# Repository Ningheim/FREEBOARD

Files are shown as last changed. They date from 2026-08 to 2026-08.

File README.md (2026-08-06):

# FREEBOARD
A 60% RGB Backlit Keyboard with a OLED display, rotary encoder, and adjustable inclination stands.

This keyboard is powered by an Orpheus/Raspberry Pi Pico and an additional MCP23017 for extra GPIO pins. The firmware is entirely coded in [QMK](https://qmk.fm/) and the case is a little wider than a Framework 13 for reference, at about 320x165mm it's made to be compact and accessible to be used alongside a laptop. I made this because I wanted to fix a lot of things with the layout of other wormier and logitech keyboards where the keys weren't as inline as I'd hoped whilst still including function keys and appealing RGB factors.

## Here are the pictures to the project
### Intended Layout ([Plate Generator](https://kbplate.ai03.com/)):
LAYOUT

### Schematic (KiCAD):
SCHEMATIC

### PCB (KiCAD):
PCB
FINALPCB

### CASE (Onshape [[Document Link]](https://cad.onshape.com/documents/8cd69c605bee1d154198ffc3/w/f18789aa034f433dfb01300c/e/379cd418fcd399b0823d03fd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))
CASE

## Case Assembly
You can use adhesive for some of the parts but it isn't required as they should sit flush without any glue, you can also sand things down to fit flush if your 3d printed had a printing issue. All of the parts I'm naming in this section have corresponding names in the onshape document.

1. Put the `Plastic Spacer` in first, then the `Plastic Window` into the slot on the inside of the `Base Case`, The window is meant to be made out of clear material like transparent plastic or something so you can see the Silkscreen design on the bottom side of the board.
2. Cut a two 1mm diameter rods to 64mm and Thread each one through the holes of each set of tilt stands you as shown in the assembly tab on the onshape document. The stands should be able to turn/revolve around the axis of the rods, and you can make the rods of any material it just has to be firm. To lock the rods in, melt plastic or insert rubber friction pads into each of the 6 empty rectangular indents on the back of the `Base Case`
3. Then you can put in the PCB with the `Plate` ontop of it. Now we have the `Top Cover` and `Translucent Emblem` left, so put the `Translucent Emblem` into the matching cutout on the `Top Cover`, and insert those joined pieces into the top of the case, to keep everything pressed down. Lastly, add the encoder knob and you're done!

## How To Flash
Freeboard uses QMK Firmware running on a Raspberry Pi Pico. The firmware source is available in firmware/freeboard.

The firmware supports:
An 81-key matrix
91 SK6812MINI-E RGB LEDs
An I2C OLED display
A rotary encoder connected through an MCP23017 GPIO expander
Media and RGB controls through a function layer

To start building the firmware, install and configure the QMK development environment, then copy the Freeboard firmware into your QMK installation:

cp -a firmware/freeboard ~/qmk_firmware/keyboards/
cd ~/qmk_firmware
qmk clean
qmk compile -kb freeboard -km default

After a successful build, the flashable firmware will be located at:

~/qmk_firmware/freeboard_default.uf2

#### Flashing Sequence
Unplug Freeboard from the computer.
Hold the BOOTSEL button on the Raspberry Pi Pico.
While continuing to hold BOOTSEL, connect the keyboard to the computer using USB.
Release BOOTSEL when a removable drive named RPI-RP2 appears.
Copy freeboard_default.uf2 onto the RPI-RP2 drive.
The drive will disconnect automatically and the keyboard will restart with the new firmware.
Flashing future updates

Hold Fn and press Esc to enter the RP2040 bootloader. When the RPI-RP2 drive appears, copy the newly compiled freeboard_default.uf2 onto it.

## CONTROLS
The Fn key is located between Right Alt and Left Arrow.

Input	Action
Rotate encoder	Adjust volume
Press encoder	Mute or unmute
Fn + Esc	Enter the bootloader
Fn + Home	Toggle RGB lighting
Fn + Page Up	Select the next RGB effect
Fn + Page Down	Select the previous RGB effect
Fn + Up	Increase RGB brightness
Fn + Down	Decrease RGB brightness
Fn + Left	Decrease RGB hue
Fn + Right	Increase RGB hue
Fn + End	Increase RGB animation speed
RGB brightness is limited in firmware because all 91 LEDs are powered from USB VBUS. Increasing the limit could exceed the available USB current.

## BOM
| Item | Cost |
|---|---|
| PCB | $37.84 |
| Switches, Keycaps, Encoder, Display | $15.00 |
| Plastic Case | Free (Printing Legion) |
| Electronic Components | $22.18 |
| Display Connector | $7.00 |
| Buffer for shipping and fees | $5.00 |
| **Total** | **~$88.02** |

Note: The BOM file itself is in ~\FREEPCB\PRODUCTION, and the keycaps, switches, stabilizers, and encoder all probably have to be bought from an external retailer. So prices may vary.

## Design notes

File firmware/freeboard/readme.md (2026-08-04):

# Freeboard

Custom 81-key keyboard using a Raspberry Pi Pico, 91 SK6812MINI-E LEDs,
an I2C OLED, and a rotary encoder connected through an MCP23017 expander.

* Keyboard Maintainer: [Freedom Nyadroh](https://github.com/ningheim)
* Controller: Raspberry Pi Pico (RP2040)
* Matrix: 6 rows by 15 columns, COL2ROW
* RGB: 91 serial LEDs on GP21 (81 key lights and 10 decorative lights)
* I2C: I2C1 on GP22/GP26
* Encoder: MCP23017 address 0x20, GPA0/GPA1/GPA2

Make example for this keyboard (after setting up your build environment):

    make freeboard:default

Flashing example for this keyboard:

    make freeboard:default:flash

See the [build environment setup](https://docs.qmk.fm/#/getting_started_build_tools) and the [make instructions](https://docs.qmk.fm/#/getting_started_make_guide) for more information. Brand new to QMK? Start with our [Complete Newbs Guide](https://docs.qmk.fm/#/newbs).

## Installation

Copy this entire `freeboard` directory to:

    ~/qmk_firmware/keyboards/freeboard

For QMK 0.33 and newer, keep the board metadata named `keyboard.json`.
Do not rename it to `info.json`.

If QMK's own Python source was previously edited, restore it first:

    cd ~/qmk_firmware
    git restore lib/python/qmk/keyboard.py

Then verify and compile:

    qmk clean
    qmk list-keyboards | grep freeboard
    qmk compile -kb freeboard -km default

The compiled UF2 should be placed in the root of the QMK firmware directory.

## Default controls

The encoder changes volume and its push switch toggles mute. Hold the key
immediately to the left of the arrow cluster to access the Fn layer. The Fn
layer contains RGB controls; Fn+Esc enters the RP2040 bootloader.

The OLED configuration assumes the common 128x32 SSD1306 display at address
0x3C. For a 128x64 display, add `#define OLED_DISPLAY_128X64` to `config.h`.

## RGB power limit

The PCB powers all 91 LEDs from USB VBUS. Firmware therefore limits the maximum
RGB brightness. Raising this limit can exceed the USB port's current budget,
especially with white or pale effects.

## Bootloader

Enter the bootloader in 3 ways:

* **Bootmagic reset**: Hold down the key at (0,0) in the matrix (usually the top left key or Escape) and plug in the keyboard
* **Physical reset button**: Briefly press the button on the back of the PCB - some may have pads you must short instead
* **Keycode in layout**: Press the key mapped to `QK_BOOT` if it is available

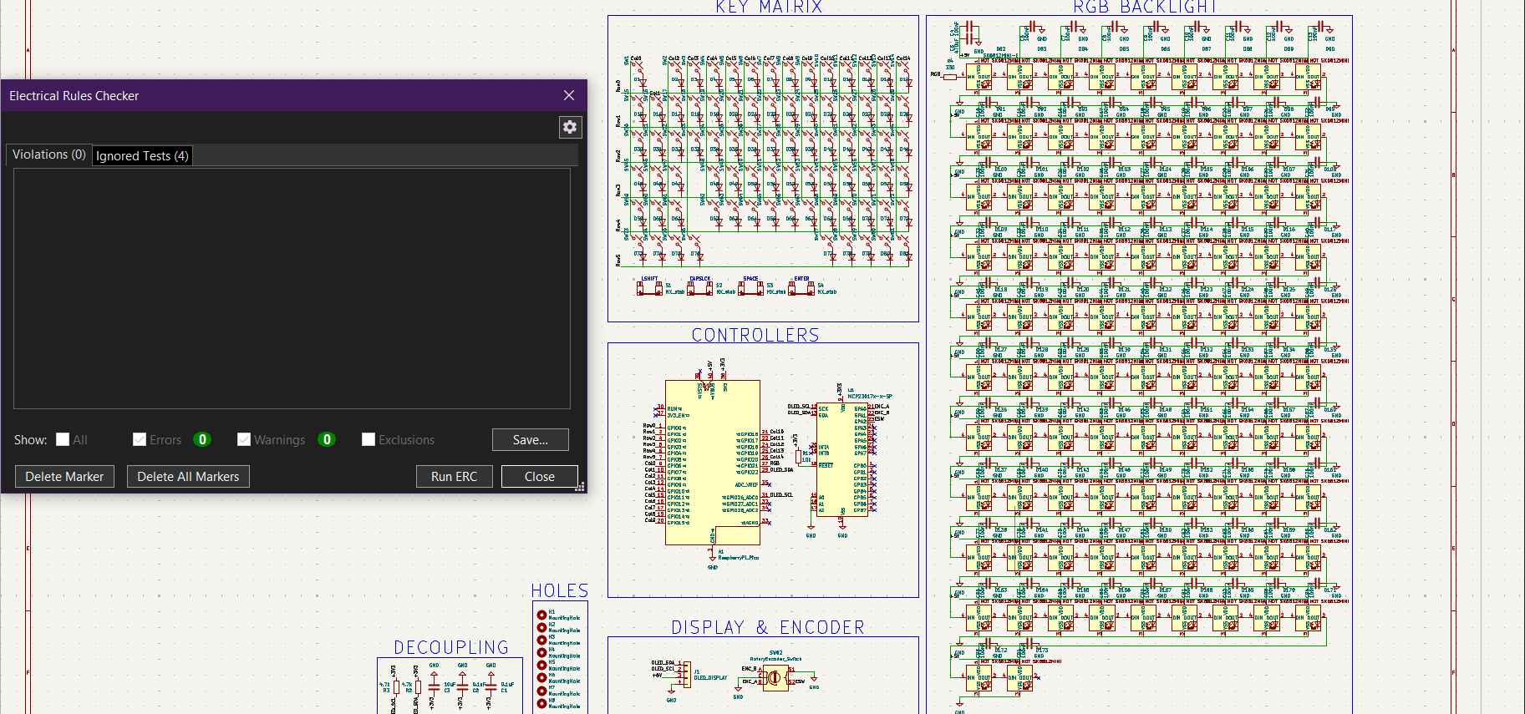
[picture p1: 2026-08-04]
FREEASSETS/SCHEMATIC.png

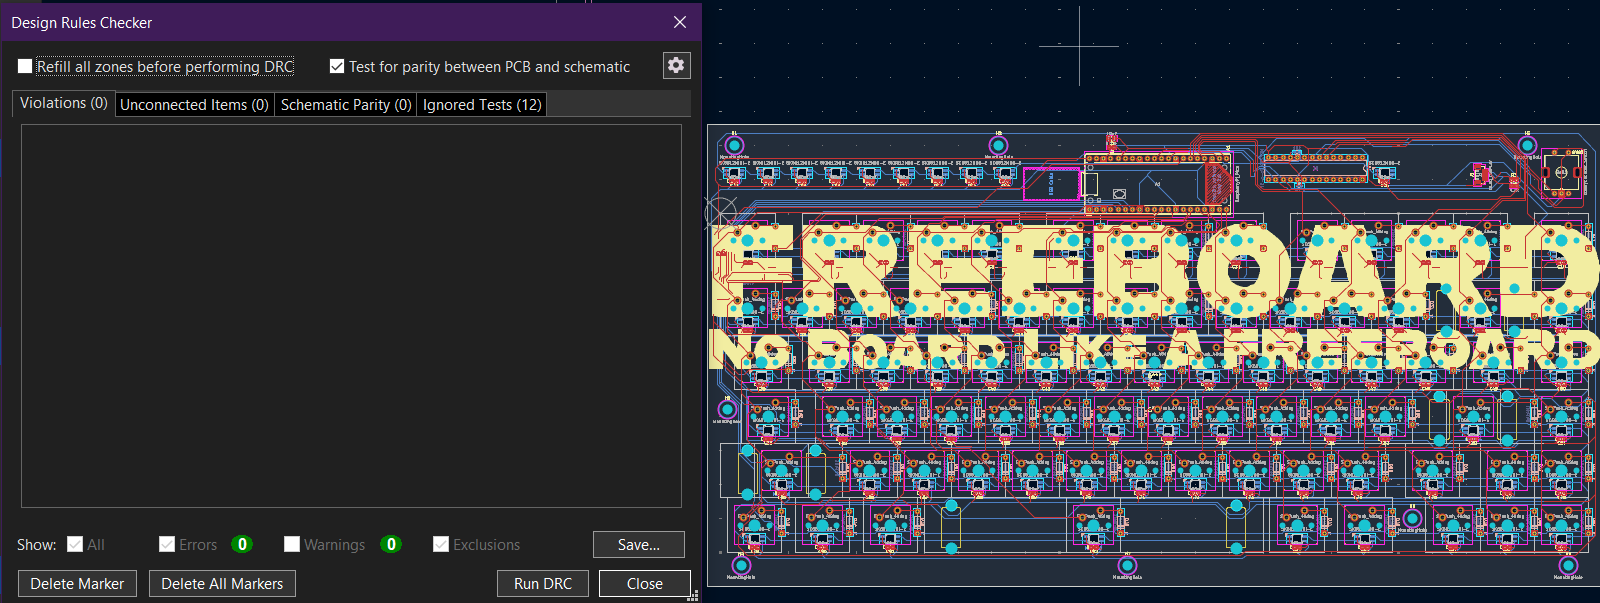
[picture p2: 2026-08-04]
FREEASSETS/PCB.png

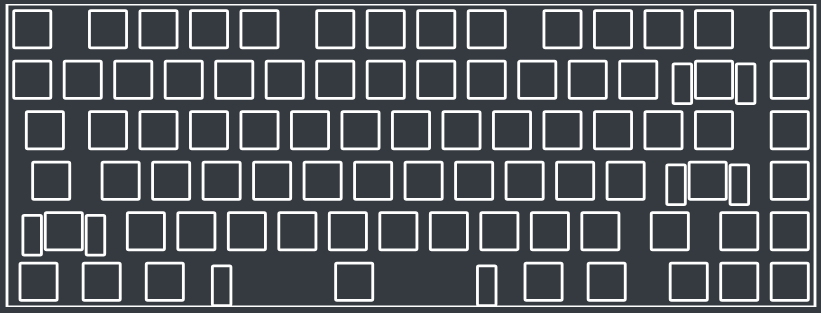
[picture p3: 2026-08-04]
FREEASSETS/LAYOUT.png

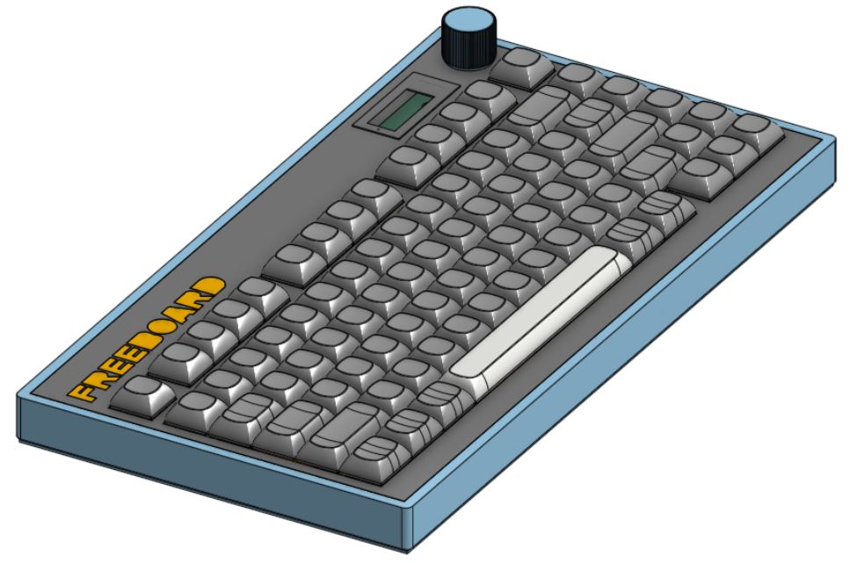
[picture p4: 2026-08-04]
FREEASSETS/CASE.png

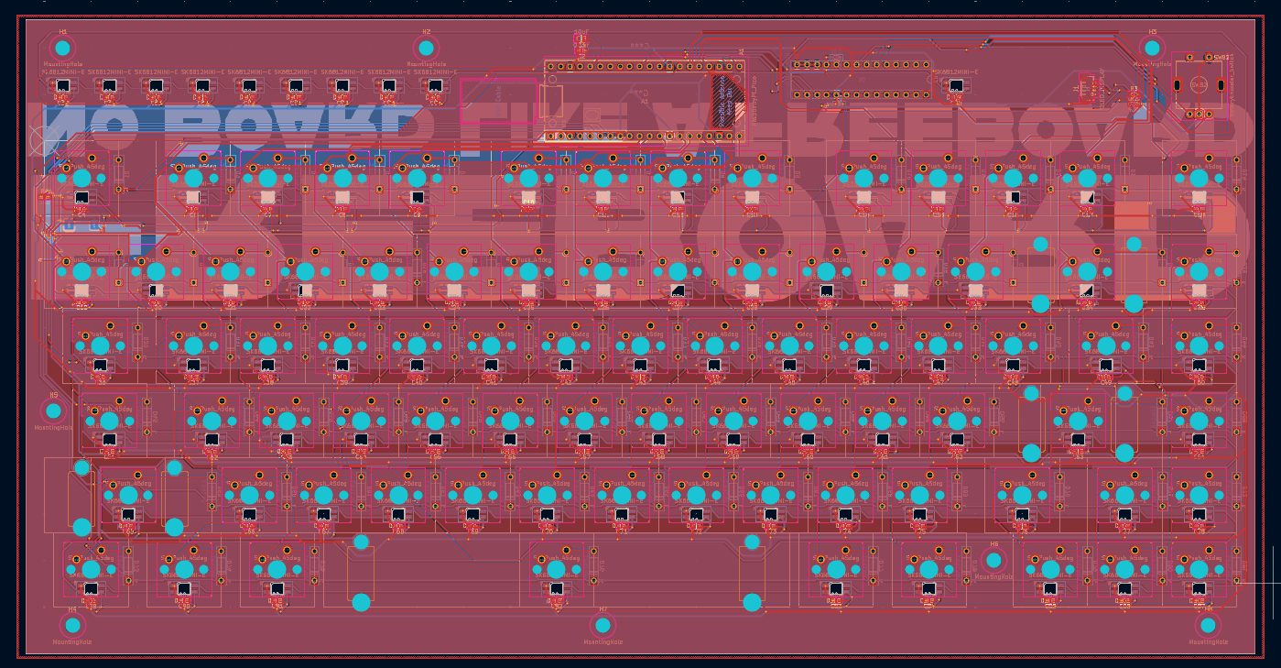
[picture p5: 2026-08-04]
FREEASSETS/FINALPCB.png

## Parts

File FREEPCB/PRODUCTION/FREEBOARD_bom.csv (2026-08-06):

Designator | Footprint | Quantity | Value | LCSC Part # | Link
A1 | RaspberryPi_Pico_Common_THT | 1 | RaspberryPi_Pico | C7203003 | https://www.lcsc.com/product-detail/C7203003.html?s_z=n_q_raspberry%2520pi%2520pico
C1, C2 | 603 | 2 | 0.1uF | C19185645 | https://www.lcsc.com/product-detail/C19185645.html?s_z=n_q_C19185645&globalKeyword=C19185645
C10, C11, C12, C13, C14, C15, C16, C17, C18, C19, C20, C21, C22, C23, C24, C25, C26, C27, C28, C29, C30, C31, C32, C33, C34, C35, C36, C37, C38, C39, C4, C40, C41, C42, C43, C44, C45, C46, C47, C48, C49, C50, C51, C52, C53, C54, C55, C56, C57, C58, C59, C6, C60, C61, C62, C63, C64, C65, C66, C67, C68, C69, C7, C70, C71, C72, C73, C74, C75, C76, C77, C78, C79, C8, C80, C81, C82, C83, C84, C85, C86, C87, C88, C89, C9, C90, C91, C92, C93, C94, C95 | 603 | 91 | 100nF | C19185645 | https://www.lcsc.com/product-detail/C19185645.html?s_z=n_q_C19185645&globalKeyword=C19185645
C3 | 805 | 1 | 10uF | C576646 | https://www.lcsc.com/product-detail/C576646.html?s_z=n_q_C576646&globalKeyword=C576646
C5 | CP_EIA-7343-31_Kemet-D_HandSolder | 1 | 470uF | C600572 | https://www.lcsc.com/product-detail/C600572.html?s_z=n_q_C600572&globalKeyword=C600572
D1, D10, D11, D12, D13, D14, D15, D16, D17, D18, D19, D2, D20, D21, D22, D23, D24, D25, D26, D27, D28, D29, D3, D30, D31, D32, D33, D34, D35, D36, D37, D38, D39, D4, D40, D41, D42, D43, D44, D45, D46, D47, D48, D49, D5, D50, D51, D52, D53, D54, D55, D56, D57, D58, D59, D6, D60, D61, D62, D63, D64, D65, D66, D67, D68, D69, D7, D70, D71, D72, D73, D74, D75, D76, D77, D78, D79, D8, D80, D81, D9 | D_DO-35_SOD27_P7.62mm_Horizontal | 81 | 1N4148 | C258182 | https://www.lcsc.com/product-detail/C258182.html?s_z=n_q_C258182&globalKeyword=C258182
D100, D101, D102, D103, D104, D105, D106, D107, D108, D109, D110, D111, D112, D113, D114, D115, D116, D117, D118, D119, D120, D121, D122, D123, D124, D125, D126, D127, D128, D129, D130, D131, D132, D133, D134, D135, D136, D137, D138, D139, D140, D141, D142, D143, D144, D145, D146, D147, D148, D149, D150, D151, D152, D153, D154, D155, D156, D157, D158, D159, D160, D161, D162, D163, D164, D165, D166, D167, D168, D169, D170, D171, D172, D82, D83, D84, D85, D86, D87, D88, D89, D90, D91, D92, D93, D94, D95, D96, D97, D98, D99 | SK6812MINI-E_fixed | 91 | SK6812MINI-E | C5149201 | https://www.lcsc.com/product-detail/C5149201.html?s_z=n_q_C5149201&globalKeyword=C5149201
J1 | JST_SH_BM04B-SRSS-TB_1x04-1MP_P1.00mm_Vertical | 1 | OLED_DISPLAY | C160390 | https://www.lcsc.com/product-detail/C160390.html?s_z=n_q_C160390&globalKeyword=C160390
R1 | 603 | 1 | 10k | C2906982 | https://www.lcsc.com/product-detail/C2906982.html?s_z=n_q_C2906982&globalKeyword=C2906982
R2, R3 | 603 | 2 | 4.7k | C99782 | https://www.lcsc.com/product-detail/C99782.html?s_z=n_q_C99782&globalKeyword=C99782
R4 | 603 | 1 | 330 | C105881 | https://www.lcsc.com/product-detail/C105881.html?s_z=n_q_C105881&globalKeyword=C105881
S1 | STAB_MX_2u | 1 | MX_stab
S2, S3 | STAB_MX_2.25u | 2 | MX_stab
S4 | STAB_MX_6.25u | 1 | MX_stab
SW1, SW10, SW11, SW12, SW13, SW14, SW15, SW16, SW17, SW18, SW19, SW2, SW20, SW21, SW22, SW23, SW24, SW25, SW26, SW27, SW28, SW29, SW3, SW30, SW31, SW32, SW33, SW34, SW35, SW36, SW37, SW38, SW39, SW4, SW40, SW41, SW42, SW43, SW44, SW45, SW46, SW47, SW48, SW49, SW5, SW50, SW51, SW52, SW53, SW54, SW55, SW56, SW57, SW58, SW59, SW6, SW60, SW61, SW62, SW63, SW64, SW65, SW66, SW67, SW68, SW69, SW7, SW70, SW71, SW72, SW73, SW74, SW75, SW76, SW77, SW78, SW79, SW8, SW80, SW81, SW9 | SW_MX_1u | 81 | SW_Push_45deg
SW82 | ROT_Alps_EC11E-Switch | 1 | RotaryEncoder_Switch
U1 | DIP-28_W7.62mm | 1 | MCP23017x-x-SP | C558584 | https://www.lcsc.com/product-detail/C558584.html?s_z=n_q_C558584&globalKeyword=C558584

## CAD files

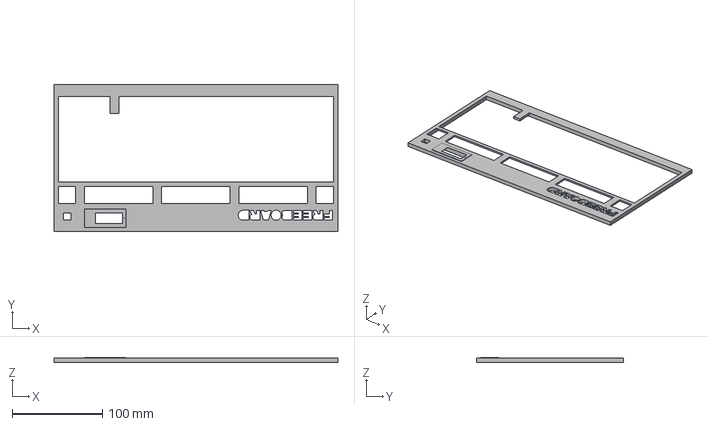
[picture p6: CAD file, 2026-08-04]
FREECAD/CASE PARTS - STEP/Case - TopCase.step
315.3 x 162.9 x 5.50 mm

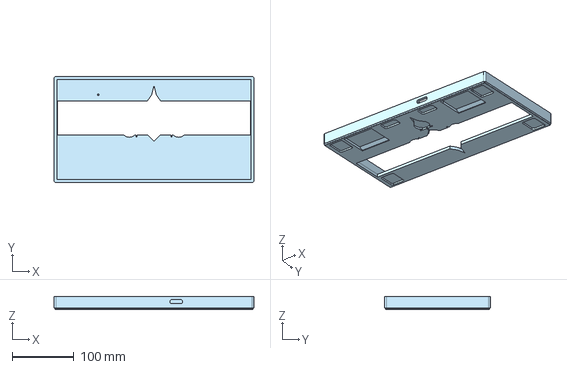
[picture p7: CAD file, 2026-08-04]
FREECAD/CASE PARTS - STEP/Case - Base Case.step
324.3 x 171.9 x 20.4 mm

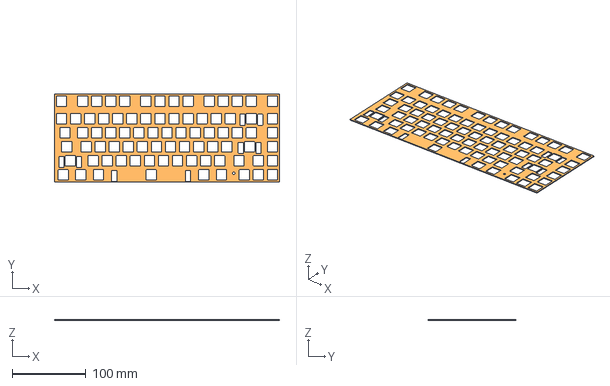
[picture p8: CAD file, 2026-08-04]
FREECAD/CASE PARTS - STEP/Case - Plate.step
304.8 x 119.1 x 1.00 mm

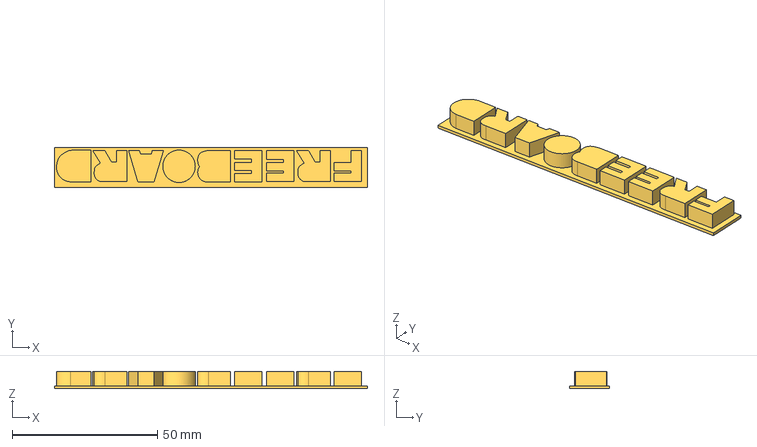
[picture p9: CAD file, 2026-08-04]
FREECAD/CASE PARTS - STEP/Case - Translucent Emblem.step
107.6 x 13.8 x 6.00 mm

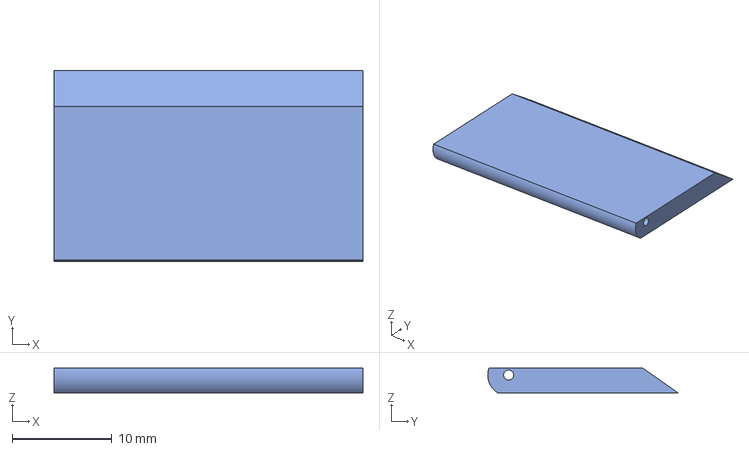
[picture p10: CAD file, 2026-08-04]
FREECAD/CASE PARTS - STEP/Case - SmallStand1.step
31.0 x 19.1 x 2.50 mm

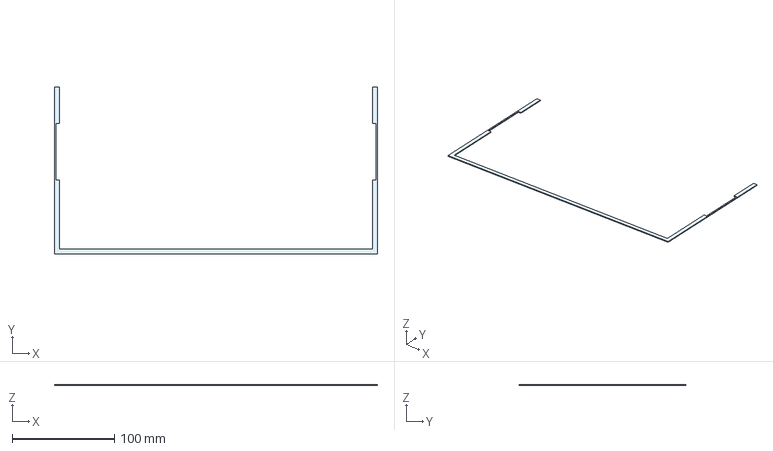
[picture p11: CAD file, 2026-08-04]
FREECAD/CASE PARTS - STEP/Case - Plastic Spacer.step
315.3 x 162.9 x 1.00 mm

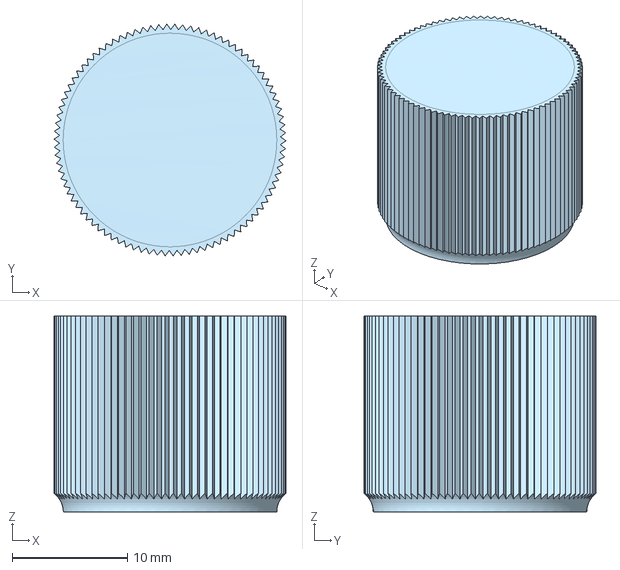
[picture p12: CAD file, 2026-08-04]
FREECAD/CASE PARTS - STEP/Case - Encoder Knob.step
20.2 x 20.1 x 17.0 mm

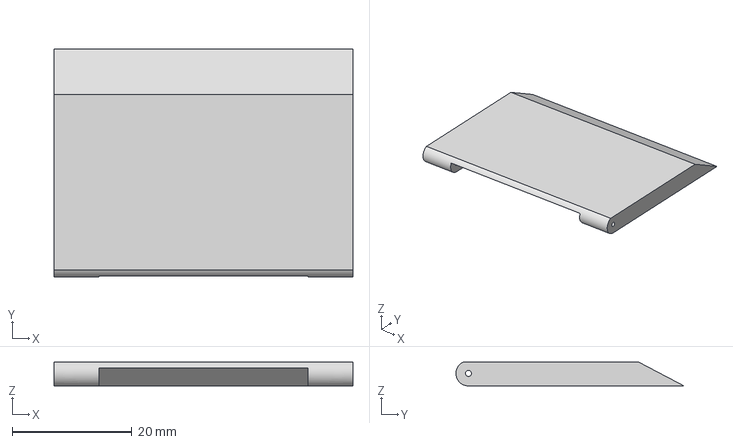
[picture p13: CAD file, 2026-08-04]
FREECAD/CASE PARTS - STEP/Case - BigStand2.step
50.0 x 38.1 x 4.00 mm

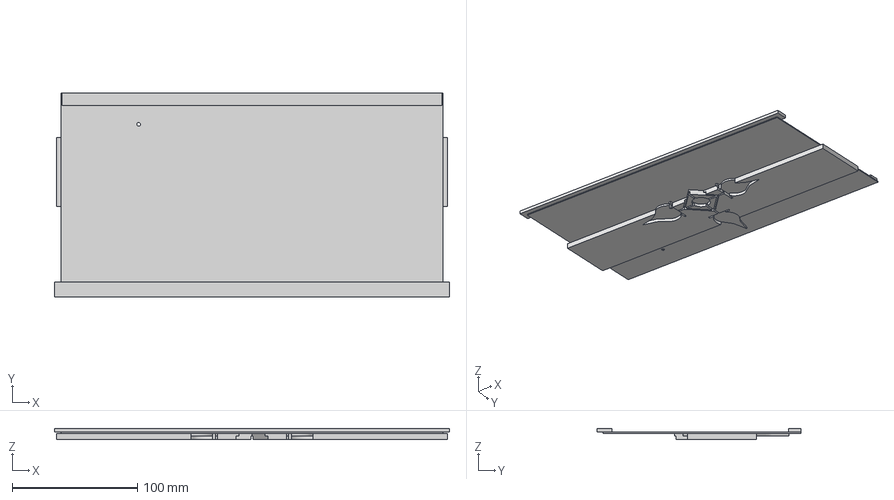
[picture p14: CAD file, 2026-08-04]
FREECAD/CASE PARTS - STEP/Case - Plastic Window.step
315.3 x 162.9 x 9.06 mm

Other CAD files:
FREECAD/CASE PARTS - STEP/Case - SmallStand2.step
FREECAD/CASE PARTS - STEP/Case - BigStand1.step
FREECAD/CASE PARTS - STL/Case - Base Case.stl
FREECAD/CASE PARTS - STL/Case - BigStand1.stl
FREECAD/CASE PARTS - STL/Case - BigStand2.stl
FREECAD/CASE PARTS - STL/Case - Encoder Knob.stl
FREECAD/CASE PARTS - STL/Case - Plastic Spacer.stl
FREECAD/CASE PARTS - STL/Case - Plastic Window.stl
FREECAD/CASE PARTS - STL/Case - Plate.stl
FREECAD/CASE PARTS - STL/Case - SmallStand1.stl
FREECAD/CASE PARTS - STL/Case - SmallStand2.stl
FREECAD/CASE PARTS - STL/Case - TopCase.stl
FREECAD/CASE PARTS - STL/Case - Translucent Emblem.stl

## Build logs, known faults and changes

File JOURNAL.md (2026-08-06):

# 7/27/2026
[LAPSE](https://lapse.hackclub.com/timelapse/CAK7ywI3q3qV)

**Total time spent: 3 hours**

I studied keyboard anatomy and creation for a while before starting this project. I now know I need three things to actually make this keyboard:

- **PCB**
- **Plate**
- **Case**

And as simple as that makes it look, I know it will be a long a grueling process especially since this is the first real keyboard I've made. Today I finished the keyboard matrix, taking inspiration from the Wormier 60% and 65% keyboards for the layout I mapped below:



Next session I'll be routing the RGB LEDs, OLED display, rotary encoder, and external SoM connector in the schematic.

The layout is a 60%-style board with the function row and PrintScreen key included. It'll have a small margin at the top for an RGB text badge reading "FREEBOARD," along with an OLED screen and a backlit rotary encoder. There will also be a dedicated LED for Caps Lock indication. I took some inspiration from the Logitech G PRO keyboard I currently use, just scaled down a bit. My goal is for this keyboard to sit on top of a Framework 13's keyboard, for gaming and general use.

This was a pretty difficult process, but I'm super excited and feeling good about the progress so far.

*(Also, sorry about the video playing during the lapse, I was watching Mat Armstrong to stay sane through the whole process.)*

# 7/28/2026
[LAPSE](https://lapse.hackclub.com/timelapse/dE8z8UnWDV4i) [LAPSE](https://lapse.hackclub.com/timelapse/KWQZoNLu7TrB)

**Total time spent: 4 hours**

Made a lot of nice progress with tracing. I troubleshot the switch matrix and I believe it's good as of now. It's easily subject to change after I add the rotary encoder. I'm not exactly sure how I'm supposed to incorporate the encoder right now. All of the other components are pretty straightforward except for that. I'm running out of pins on the Pico so I'm searching for ways to conserve as many as possible. Today I got Claude to help me code a JSON for a keyboard switch layout/plate and I finally got it looking a little more professional. Here's the polished version of what my keyboard layout will look like:



Once I get a response in the channel for help with wiring the power bus lines and the rotary encoder I'll resume and finish off the schematic process for now. I'm liking how it all looks so far. This is the schematic as of right now, once I finish the schematic I'll separate all the groups and finalize the organization of the file:



**Okay it's me 15 hours later**, I made tremendous progress with the Schematic and I was able to almost completely finish the schematic. I haven't assigned footprints yet but everything went extremely well this session. I implemented resistors and capacitors wherever I needed them. I found out I needed them by looking at other submissions to Keeb and asking Claude a few questions. Speaking of Claude, it told me to add a fuse to the VBUS so the PCB I plan on connecting this stuff to wont completely self destruct if the RGB LEDs go crazy. But every time I added the fuse it kept giving me an error so for now I'm sticking with the error-less design. Next session I'll look into the whole fuse idea a little harder and I'll determine whether or not I'll use it; I'll also add footprints to everything and finally start working on laying out traces for the physical PCB. We're almost there!



# 7/29/2026
[LAPSE](https://lapse.hackclub.com/timelapse/rfvNHJk3dFeS)[LAPSE](https://lapse.hackclub.com/timelapse/_yMK92cxTNwy) 

**Total time spent: 6 hours**

Today I finalized the schematic and footprints.



Took me an hour to do it because I had some trouble with the fuse idea from earlier. I found out that the fuse isn't really necessary. I also understand that I could have added a 33ohm resistor in between each LED's data pins but i decided not to do that since it'd be a pain to handsolder. And I'm going to be adding mill-max hotswap sockets to my finished build. So I hope I get funded for that. I was told I would be funded for everything that would necessarily impact my project. Right now I'll list all the ammenities and complexities I decided to add to the project:
- Per-Key Backlight
- Caps Lock Indicator
- Backlit Branding Logo
- Rotary Encoder
- OLED Display
- Hotswappable Switches

Anyways later today I'll work on the PCB design itself. I'll ask around if there's anything wrong with how I made the schematic but I think I'll be moving on now!

**Its around midnight now** I got done with a 4-5 hour session and i finished organizing everything and whatnot. The board organization is 90% done but i need some rest. Tomorrow I'll finish organizing the components in a few minutes and finally start routing.



# 7/30/2026
[LAPSE](https://lapse.hackclub.com/timelapse/d9UfakixuzQQ)

**Total time spent: 6 hours**

Just started routing the PCB. It is not looking good at all. My organization is great though, but when I finished it all and went to fill the copper layer I got hundreds of errors and warnings. This was really discouraging but I know it isn't to important since all of my layouts and traces should be connected. I'll look over it again tomorrow. I suspect it's because I didn't put traces or Vias on any of the GND pads believing the layer fill would connect them all automatically. I'll try to do it manually later on.. Anyways the lapse feature has been working pretty well recently! I haven't gotten any corrupt or inaccessible files after strictly doing lapses from lapse.hackclub.com instead of any other embed or site, but, accidentally of course, I took a break to scroll tiktok and play games without pausing the recording so instead of 5 hours and 48 minutes its more like only 5 hours.



# 7/31/2026
[LAPSE](https://lapse.hackclub.com/timelapse/Ccc565L8SkLy)

**Total time spent: 4 hours**

Finished 3D modelling the PCB. it took a while but it looks extremely nice, I quickly learned how to add 3d models to a global footprint instead of editing each switch's individual one. I got the DSA keycap models from a reddit post. This is the [link](https://drive.google.com/drive/u/0/folders/0B0LNjZf_tzjWZGhwZ0VKUm9PQVE?resourcekey=0-rYUAMYD1-22Btlgdmpb0IQ) I'm really grateful to the creator. Anyways it looks like this now with all the components (Minus the oled display) modeled:



I swapped out the OLED display footprint for a `Stemma QT 4-Pin Female Connector` Because I decided I was going to connect my display via a `Header to QT` style cable from Adafruit. And in doing this, I allow the connection between the OLED display and my PCB to be a lot more flexible which would allow me to prop the display up on an incline as seen on Wormier's keyboards (I took a lot of inspiration from them, I love their designs) as seen below:



This would be both aesthetically pleasing and gives the display a little more accessibility. And now I'm tackling the GND plane issue. It took me a while to understand but now I realize I just have to connect all the GND pads together and then do the ground pour to leave no room for errors about my GND connection. I've routed about 45% of the GND net so far and once I finish this I will be able to finally move onto the Case design which I'm pretty excited for. I'm going to make this keyboard near perfect to actually use it in place of my current TKL one. Here's how the PCB looks now (I know, beautiful 🥹) :



# 8/1/2026
[LAPSE](https://lapse.hackclub.com/timelapse/lMde7KmQML3c) [LAPSE](https://lapse.hackclub.com/timelapse/M3SkIIiRgxoi)

**Total time spent: 12 hours**

Finally completed the PCB within the first hour of this lapse. Spent the rest modelling the case. I'm double, triple, and quadruple checking each part of my layout just to make sure I don't have any miscalculations or inconsistencies with my work. This is how the finished PCB looked:



I'm modelling the case design in Onshape and I guess I'll submit an assembly demo with push-able keys later. Ok scratch that onshape is already struggling on my laptop I doubt adding push-able mates is necessary. Anyways I just finished the bottom plate of my case (for the most part) and it looks amazing imo. I'm adding a transparent plastic window in my next session but it looks like this now at 10mm of thickness:



It looks great and I'm really happy about how I added the 2 stage stands at the top, I hope they work but yeah this is basically it for now.

# 8/2/2026
[LAPSE](https://lapse.hackclub.com/timelapse/Tz_bAdnx_3QB) [LAPSE](https://lapse.hackclub.com/timelapse/NqZxc6qf-A2T)

**Total time spent: 6 hours**

I finished the entire Board body in about an hour. I'm moving onto the Firmware now. I finished modelling the Rotary Encoder Knob and Recessed the OLED Display panel a little more to allow this to keep it's low-(ish) profile silhouette. 



> Also, for anyone that's looking to model their keyboard like I did with mine, I found the DSA profile models in a Reddit thread which I'm super grateful for. Here's the google [drive link](https://drive.google.com/drive/u/0/folders/0B0LNjZf_tzjWZGhwZ0VKUm9PQVE?resourcekey=0-rYUAMYD1-22Btlgdmpb0IQ)

And I forgot to generate the BOM and fabrication files for JLCPCB or PCBWAY so I made sure to do that. Also I forgot to add the copper fill layer, it wouldn't really be that bad if I left it out but I guess it's always optimal to do so, here's how it looked:



Ok, just finished the second lapse. I'm absolutely livid at how terrible Gemini is as an LLM. It kept recommending things and making me go down rabbit holes that were completely unrelated and I had to use Gemini because I ran out of Claude credits 😭 I spent 4 hours of my life coding a dysfunctional firmware because Gemini is so redundant it's actually crazy bro. Anyway I at least mapped the keys into the JSON dictionary and I reverted the files mostly to before I started getting baited by Gemini. I'm honestly just happy I can start from a feasible position now because the amount of time I just wasted is insane. I'm sticking to Claude for life. 

# 8/3/2026
[LAPSE](https://lapse.hackclub.com/timelapse/1gnXPpYtZCP9)

**Total time spent: 1 hour**

Just some housekeeping adjustments made to the onshape file. Also I realized I forgot to share the link to the native onshape document, [so here it is](https://cad.onshape.com/documents/8cd69c605bee1d154198ffc3/w/f18789aa034f433dfb01300c/e/379cd418fcd399b0823d03fd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). I fixed some interference issues I noticed in assembly, they werent that important but I'm just making sure everything fits together smoothly. Specifically I made holes to accommodate for the hardware components a little more fairly. Took a break and failed to resume the lapse yet again though. Sad stuff


# 8/4/2026
[LAPSE](https://lapse.hackclub.com/timelapse/J0E3boF5okCd) [LAPSE](https://lapse.hackclub.com/timelapse/QhkDZo6vc7pb)

**Total time spent: 4 hours**

Just finished calculating how much this would cost, with the BOM and everything. Here are the results:

| Item | Cost |
|---|---|
| PCB | $37.84 |
| Switches, Keycaps, Encoder, Display | $15.00 |
| Plastic Case | Free (Printing Legion) |
| Electronic Components | $22.18 |
| Display Connector | $7.00 |
| Buffer for shipping and fees | $5.00 |
| **Total** | **~$88.02** |

So not that bad. I hope I have enough currency leftover to buy some RAM. Anyways, I'll be working on the Firmware later today.
A couple minutes after and I finished the firmware and the readme is complete. I'm just getting ready to ship now. I forgot to lapse I think all this time is taking a hit on my health dawg. This time I lost a lot more time though so I'll use my hackatime tracker as proof of everything:


Also the firmware:


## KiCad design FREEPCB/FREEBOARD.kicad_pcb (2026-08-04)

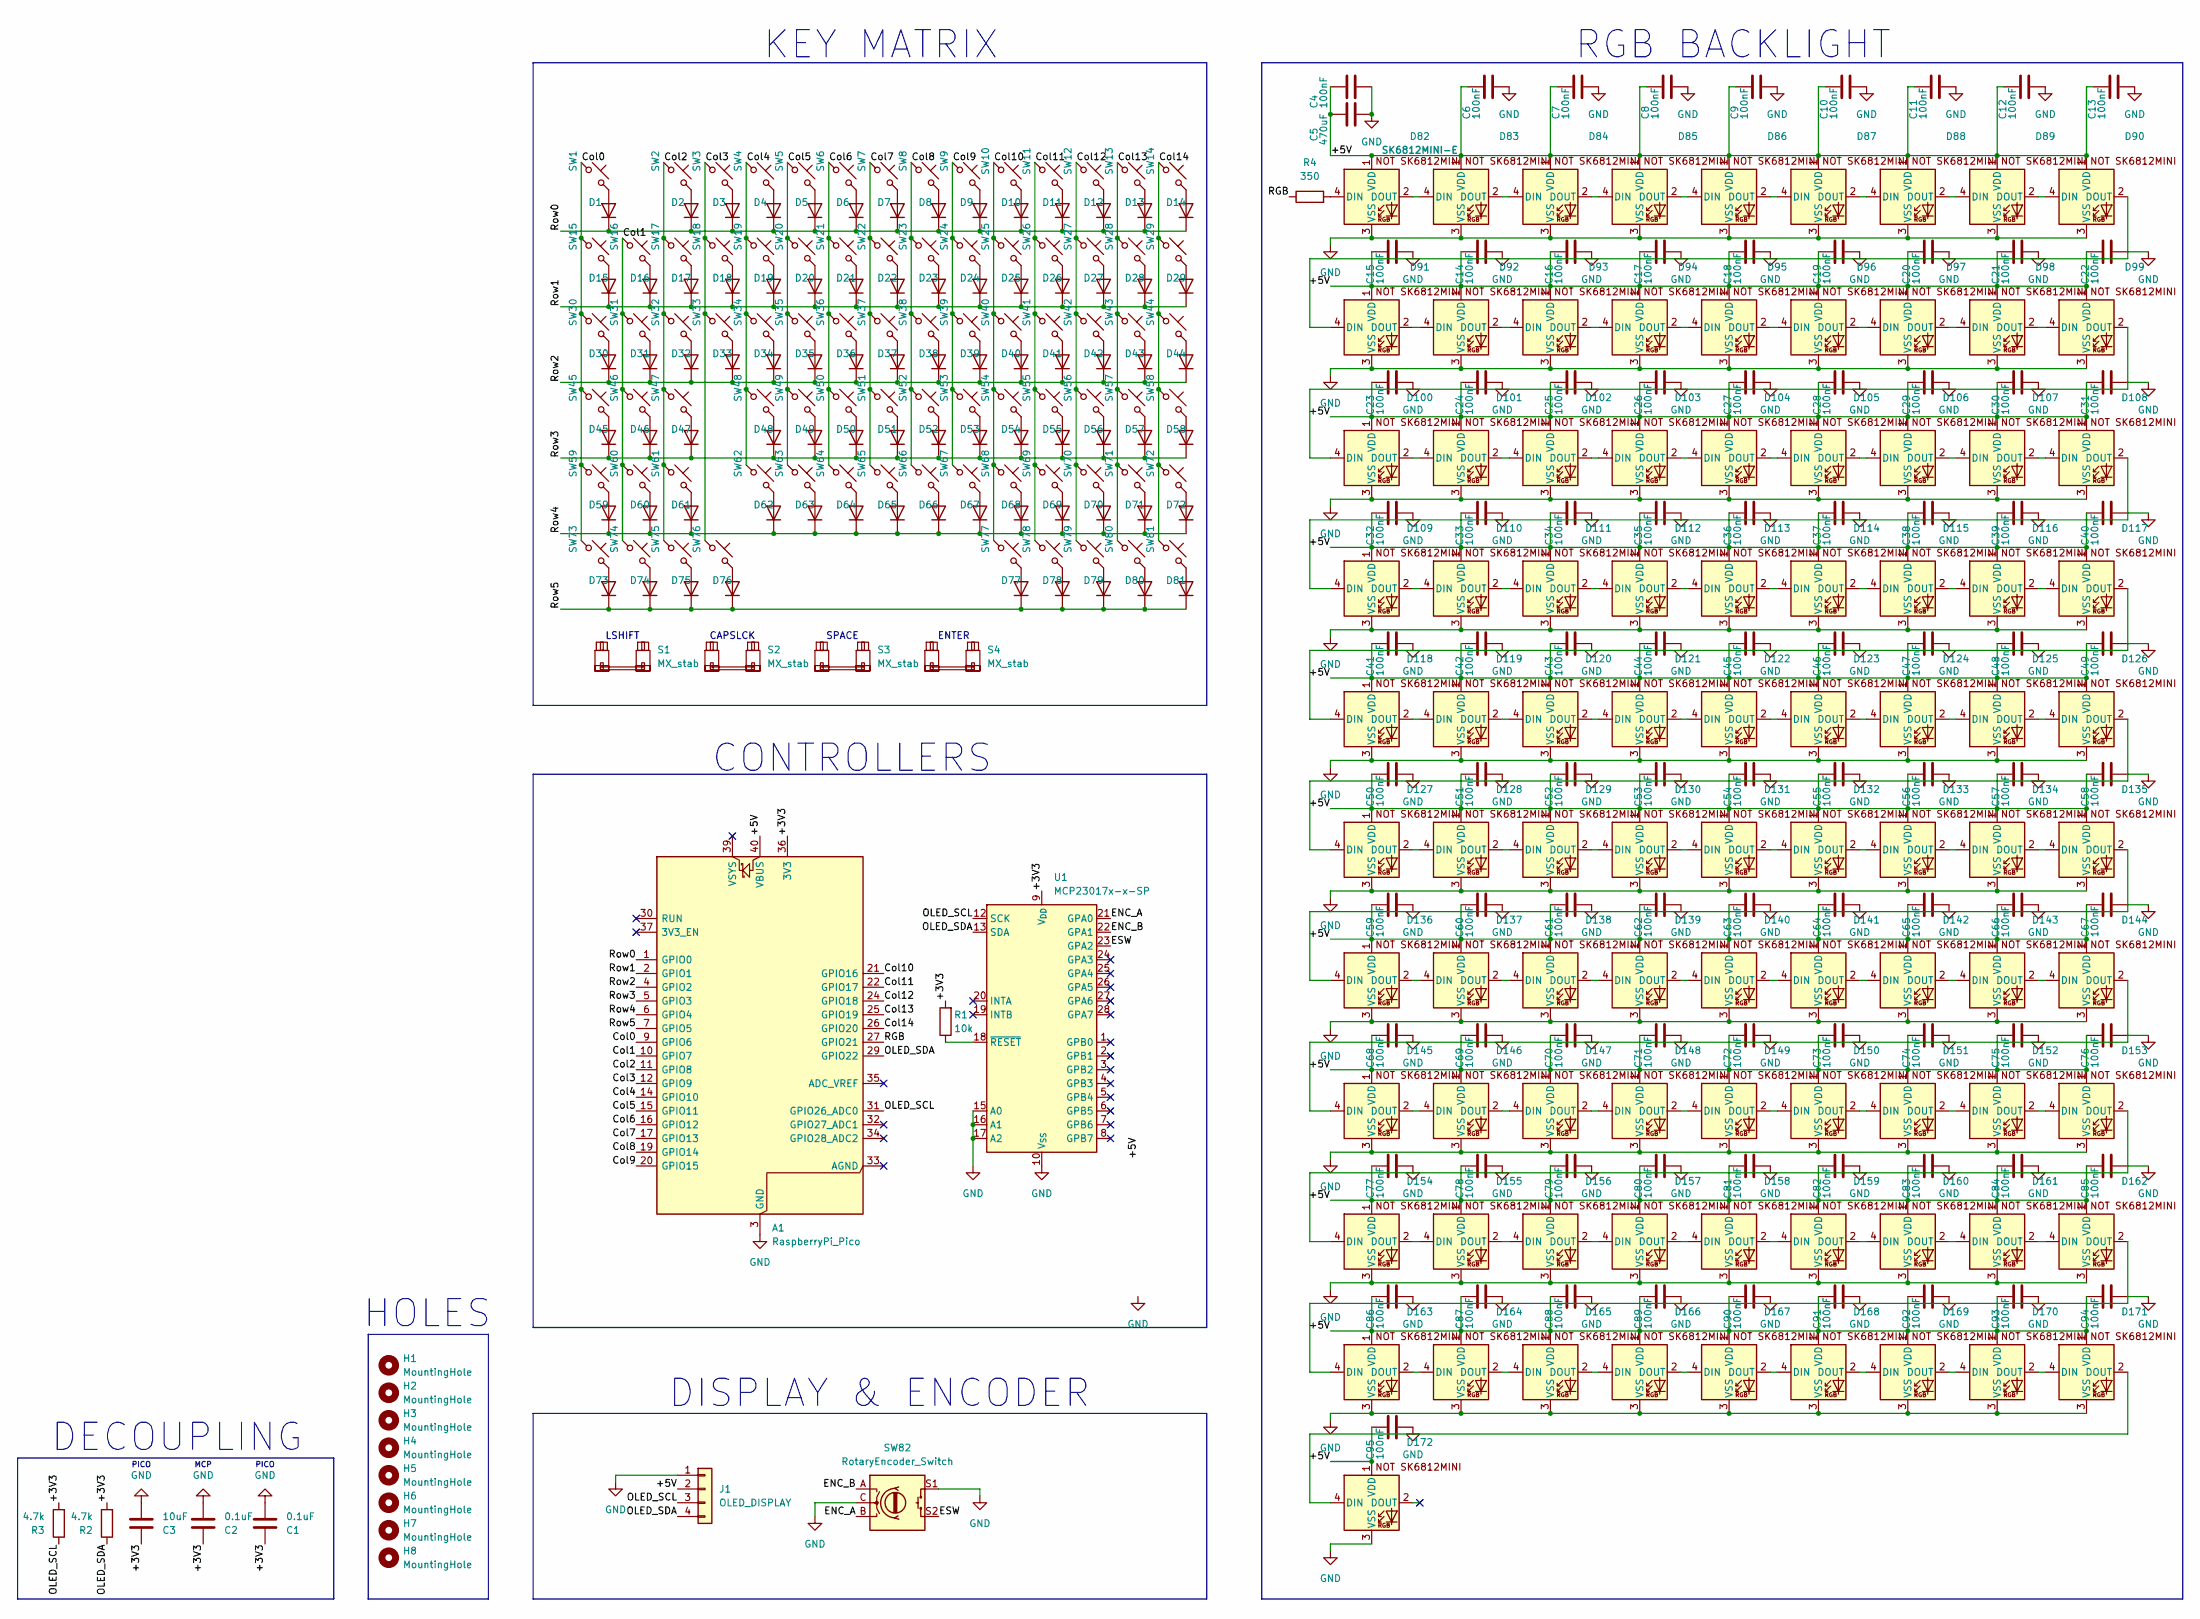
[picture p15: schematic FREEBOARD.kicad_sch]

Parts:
A1: RaspberryPi_Pico; RaspberryPi_Pico_Common_THT
C1, C2: 0.1uF; C_0603_1608Metric_Pad1.08x0.95mm_HandSolder
C3: 10uF; C_0805_2012Metric_Pad1.18x1.45mm_HandSolder
C4, C6, C7, C8, C9, C10, C11, C12, C13, C14, C15, C16, C17, C18, C19, C20, C21, C22, C23, C24, C25, C26, C27, C28, C29, C30, C31, C32, C33, C34, C35, C36, C37, C38, C39, C40, C41, C42, C43, C44, C45, C46, C47, C48, C49, C50, C51, C52, C53, C54, C55, C56, C57, C58, C59, C60, C61, C62, C63, C64, C65, C66, C67, C68, C69, C70, C71, C72, C73, C74, C75, C76, C77, C78, C79, C80, C81, C82, C83, C84, C85, C86, C87, C88, C89, C90, C91, C92, C93, C94, C95: 100nF; C_0603_1608Metric_Pad1.08x0.95mm_HandSolder
C5: 470uF; CP_EIA-7343-31_Kemet-D_HandSolder
D1, D2, D3, D4, D5, D6, D7, D8, D9, D10, D11, D12, D13, D14, D15, D16, D17, D18, D19, D20, D21, D22, D23, D24, D25, D26, D27, D28, D29, D30, D31, D32, D33, D34, D35, D36, D37, D38, D39, D40, D41, D42, D43, D44, D45, D46, D47, D48, D49, D50, D51, D52, D53, D54, D55, D56, D57, D58, D59, D60, D61, D62, D63, D64, D65, D66, D67, D68, D69, D70, D71, D72, D73, D74, D75, D76, D77, D78, D79, D80, D81: 1N4148; D_DO-35_SOD27_P7.62mm_Horizontal
D82, D83, D84, D85, D86, D87, D88, D89, D90, D91, D92, D93, D94, D95, D96, D97, D98, D99, D100, D101, D102, D103, D104, D105, D106, D107, D108, D109, D110, D111, D112, D113, D114, D115, D116, D117, D118, D119, D120, D121, D122, D123, D124, D125, D126, D127, D128, D129, D130, D131, D132, D133, D134, D135, D136, D137, D138, D139, D140, D141, D142, D143, D144, D145, D146, D147, D148, D149, D150, D151, D152, D153, D154, D155, D156, D157, D158, D159, D160, D161, D162, D163, D164, D165, D166, D167, D168, D169, D170, D171, D172: SK6812MINI-E; SK6812MINI-E_fixed
H1, H2, H3, H4, H5, H6, H7, H8: MountingHole; MountingHole_3.2mm_M3
J1: OLED_DISPLAY; JST_SH_BM04B-SRSS-TB_1x04-1MP_P1.00mm_Vertical
R1: 10k; R_0603_1608Metric_Pad0.98x0.95mm_HandSolder
R2, R3: 4.7k; R_0603_1608Metric_Pad0.98x0.95mm_HandSolder
R4: 350; R_0603_1608Metric_Pad0.98x0.95mm_HandSolder
S1: MX_stab; STAB_MX_2u
S2, S3: MX_stab; STAB_MX_2.25u
S4: MX_stab; STAB_MX_6.25u
SW1, SW2, SW3, SW4, SW5, SW6, SW7, SW8, SW9, SW10, SW11, SW12, SW13, SW14, SW15, SW16, SW17, SW18, SW19, SW20, SW21, SW22, SW23, SW24, SW25, SW26, SW27, SW28, SW29, SW30, SW31, SW32, SW33, SW34, SW35, SW36, SW37, SW38, SW39, SW40, SW41, SW42, SW43, SW44, SW45, SW46, SW47, SW48, SW49, SW50, SW51, SW52, SW53, SW54, SW55, SW56, SW57, SW58, SW59, SW60, SW61, SW62, SW63, SW64, SW65, SW66, SW67, SW68, SW69, SW70, SW71, SW72, SW73, SW74, SW75, SW76, SW77, SW78, SW79, SW80, SW81: SW_Push_45deg; SW_MX_1u
SW82: RotaryEncoder_Switch; ROT_Alps_EC11E-Switch
U1: MCP23017x-x-SP; DIP-28_W7.62mm

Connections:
/+3V3: A1.36 (3V3), C1.1, C2.1, C3.1, R1.2, R2.2, R3.2, U1.9 (V_{DD})
/+5V: A1.40 (VBUS), C4.1, C5.1, C6.1, C7.1, C8.1, C9.1, C10.1, C11.1, C12.1, C13.1, C14.1, C15.1, C16.1, C17.1, C18.1, C19.1, C20.1, C21.1, C22.1, C23.1, C24.1, C25.1, C26.1, C27.1, C28.1, C29.1, C30.1, C31.1, C32.1, C33.1, C34.1, C35.1, C36.1, C37.1, C38.1, C39.1, C40.1, C41.1, C42.1, C43.1, C44.1, C45.1, C46.1, C47.1, C48.1, C49.1, C50.1, C51.1, C52.1, C53.1, C54.1, C55.1, C56.1, C57.1, C58.1, C59.1, C60.1, C61.1, C62.1, C63.1, C64.1, C65.1, C66.1, C67.1, C68.1, C69.1, C70.1, C71.1, C72.1, C73.1, C74.1, C75.1, C76.1, C77.1, C78.1, C79.1, C80.1, C81.1, C82.1, C83.1, C84.1, C85.1, C86.1, C87.1, C88.1, C89.1, C90.1, C91.1, C92.1, C93.1, C94.1, C95.1, D82.1 (VDD), D83.1 (VDD), D84.1 (VDD), D85.1 (VDD), D86.1 (VDD), D87.1 (VDD), D88.1 (VDD), D89.1 (VDD), D90.1 (VDD), D91.1 (VDD), D92.1 (VDD), D93.1 (VDD), D94.1 (VDD), D95.1 (VDD), D96.1 (VDD), D97.1 (VDD), D98.1 (VDD), D99.1 (VDD), D100.1 (VDD), D101.1 (VDD), D102.1 (VDD), D103.1 (VDD), D104.1 (VDD), D105.1 (VDD), D106.1 (VDD), D107.1 (VDD), D108.1 (VDD), D109.1 (VDD), D110.1 (VDD), D111.1 (VDD), D112.1 (VDD), D113.1 (VDD), D114.1 (VDD), D115.1 (VDD), D116.1 (VDD), D117.1 (VDD), D118.1 (VDD), D119.1 (VDD), D120.1 (VDD), D121.1 (VDD), D122.1 (VDD), D123.1 (VDD), D124.1 (VDD), D125.1 (VDD), D126.1 (VDD), D127.1 (VDD), D128.1 (VDD), D129.1 (VDD), D130.1 (VDD), D131.1 (VDD), D132.1 (VDD), D133.1 (VDD), D134.1 (VDD), D135.1 (VDD), D136.1 (VDD), D137.1 (VDD), D138.1 (VDD), D139.1 (VDD), D140.1 (VDD), D141.1 (VDD), D142.1 (VDD), D143.1 (VDD), D144.1 (VDD), D145.1 (VDD), D146.1 (VDD), D147.1 (VDD), D148.1 (VDD), D149.1 (VDD), D150.1 (VDD), D151.1 (VDD), D152.1 (VDD), D153.1 (VDD), D154.1 (VDD), D155.1 (VDD), D156.1 (VDD), D157.1 (VDD), D158.1 (VDD), D159.1 (VDD), D160.1 (VDD), D161.1 (VDD), D162.1 (VDD), D163.1 (VDD), D164.1 (VDD), D165.1 (VDD), D166.1 (VDD), D167.1 (VDD), D168.1 (VDD), D169.1 (VDD), D170.1 (VDD), D171.1 (VDD), D172.1 (VDD), J1.2
/Col0: A1.9 (GPIO6), SW1.1, SW15.1, SW30.1, SW45.1, SW59.1, SW73.1
/Col1: A1.10 (GPIO7), SW16.1, SW31.1, SW46.1, SW60.1, SW74.1
/Col2: A1.11 (GPIO8), SW2.1, SW17.1, SW32.1, SW47.1, SW61.1, SW75.1
/Col3: A1.12 (GPIO9), SW3.1, SW18.1, SW33.1, SW76.1
/Col4: A1.14 (GPIO10), SW4.1, SW19.1, SW34.1, SW48.1, SW62.1
/Col5: A1.15 (GPIO11), SW5.1, SW20.1, SW35.1, SW49.1, SW63.1
/Col6: A1.16 (GPIO12), SW6.1, SW21.1, SW36.1, SW50.1, SW64.1
/Col7: A1.17 (GPIO13), SW7.1, SW22.1, SW37.1, SW51.1, SW65.1
/Col8: A1.19 (GPIO14), SW8.1, SW23.1, SW38.1, SW52.1, SW66.1
/Col9: A1.20 (GPIO15), SW9.1, SW24.1, SW39.1, SW53.1, SW67.1
/Col10: A1.21 (GPIO16), SW10.1, SW25.1, SW40.1, SW54.1, SW68.1, SW77.1
/Col11: A1.22 (GPIO17), SW11.1, SW26.1, SW41.1, SW55.1, SW69.1, SW78.1
/Col12: A1.24 (GPIO18), SW12.1, SW27.1, SW42.1, SW56.1, SW70.1, SW79.1
/Col13: A1.25 (GPIO19), SW13.1, SW28.1, SW43.1, SW57.1, SW71.1, SW80.1
/Col14: A1.26 (GPIO20), SW14.1, SW29.1, SW44.1, SW58.1, SW72.1, SW81.1
/ENC_A: SW82.B, U1.21 (GPA0)
/ENC_B: SW82.A, U1.22 (GPA1)
/ESW: SW82.S2, U1.23 (GPA2)
/OLED_SCL: A1.31 (GPIO26_ADC0), J1.3, R3.1, U1.12 (SCK)
/OLED_SDA: A1.29 (GPIO22), J1.4, R2.1, U1.13 (SDA)
/RGB: A1.27 (GPIO21), R4.1
/Row0: A1.1 (GPIO0), D1.1 (K), D2.1 (K), D3.1 (K), D4.1 (K), D5.1 (K), D6.1 (K), D7.1 (K), D8.1 (K), D9.1 (K), D10.1 (K), D11.1 (K), D12.1 (K), D13.1 (K), D14.1 (K)
/Row1: A1.2 (GPIO1), D15.1 (K), D16.1 (K), D17.1 (K), D18.1 (K), D19.1 (K), D20.1 (K), D21.1 (K), D22.1 (K), D23.1 (K), D24.1 (K), D25.1 (K), D26.1 (K), D27.1 (K), D28.1 (K), D29.1 (K)
/Row2: A1.4 (GPIO2), D30.1 (K), D31.1 (K), D32.1 (K), D33.1 (K), D34.1 (K), D35.1 (K), D36.1 (K), D37.1 (K), D38.1 (K), D39.1 (K), D40.1 (K), D41.1 (K), D42.1 (K), D43.1 (K), D44.1 (K)
/Row3: A1.5 (GPIO3), D45.1 (K), D46.1 (K), D47.1 (K), D48.1 (K), D49.1 (K), D50.1 (K), D51.1 (K), D52.1 (K), D53.1 (K), D54.1 (K), D55.1 (K), D56.1 (K), D57.1 (K), D58.1 (K)
/Row4: A1.6 (GPIO4), D59.1 (K), D60.1 (K), D61.1 (K), D62.1 (K), D63.1 (K), D64.1 (K), D65.1 (K), D66.1 (K), D67.1 (K), D68.1 (K), D69.1 (K), D70.1 (K), D71.1 (K), D72.1 (K)
/Row5: A1.7 (GPIO5), D73.1 (K), D74.1 (K), D75.1 (K), D76.1 (K), D77.1 (K), D78.1 (K), D79.1 (K), D80.1 (K), D81.1 (K)
GND: A1.3 (GND), A1.8 (GND), A1.13 (GND), A1.18 (GND), A1.23 (GND), A1.28 (GND), A1.38 (GND), C1.2, C2.2, C3.2, C4.2, C5.2, C6.2, C7.2, C8.2, C9.2, C10.2, C11.2, C12.2, C13.2, C14.2, C15.2, C16.2, C17.2, C18.2, C19.2, C20.2, C21.2, C22.2, C23.2, C24.2, C25.2, C26.2, C27.2, C28.2, C29.2, C30.2, C31.2, C32.2, C33.2, C34.2, C35.2, C36.2, C37.2, C38.2, C39.2, C40.2, C41.2, C42.2, C43.2, C44.2, C45.2, C46.2, C47.2, C48.2, C49.2, C50.2, C51.2, C52.2, C53.2, C54.2, C55.2, C56.2, C57.2, C58.2, C59.2, C60.2, C61.2, C62.2, C63.2, C64.2, C65.2, C66.2, C67.2, C68.2, C69.2, C70.2, C71.2, C72.2, C73.2, C74.2, C75.2, C76.2, C77.2, C78.2, C79.2, C80.2, C81.2, C82.2, C83.2, C84.2, C85.2, C86.2, C87.2, C88.2, C89.2, C90.2, C91.2, C92.2, C93.2, C94.2, C95.2, D82.3 (VSS), D83.3 (VSS), D84.3 (VSS), D85.3 (VSS), D86.3 (VSS), D87.3 (VSS), D88.3 (VSS), D89.3 (VSS), D90.3 (VSS), D91.3 (VSS), D92.3 (VSS), D93.3 (VSS), D94.3 (VSS), D95.3 (VSS), D96.3 (VSS), D97.3 (VSS), D98.3 (VSS), D99.3 (VSS), D100.3 (VSS), D101.3 (VSS), D102.3 (VSS), D103.3 (VSS), D104.3 (VSS), D105.3 (VSS), D106.3 (VSS), D107.3 (VSS), D108.3 (VSS), D109.3 (VSS), D110.3 (VSS), D111.3 (VSS), D112.3 (VSS), D113.3 (VSS), D114.3 (VSS), D115.3 (VSS), D116.3 (VSS), D117.3 (VSS), D118.3 (VSS), D119.3 (VSS), D120.3 (VSS), D121.3 (VSS), D122.3 (VSS), D123.3 (VSS), D124.3 (VSS), D125.3 (VSS), D126.3 (VSS), D127.3 (VSS), D128.3 (VSS), D129.3 (VSS), D130.3 (VSS), D131.3 (VSS), D132.3 (VSS), D133.3 (VSS), D134.3 (VSS), D135.3 (VSS), D136.3 (VSS), D137.3 (VSS), D138.3 (VSS), D139.3 (VSS), D140.3 (VSS), D141.3 (VSS), D142.3 (VSS), D143.3 (VSS), D144.3 (VSS), D145.3 (VSS), D146.3 (VSS), D147.3 (VSS), D148.3 (VSS), D149.3 (VSS), D150.3 (VSS), D151.3 (VSS), D152.3 (VSS), D153.3 (VSS), D154.3 (VSS), D155.3 (VSS), D156.3 (VSS), D157.3 (VSS), D158.3 (VSS), D159.3 (VSS), D160.3 (VSS), D161.3 (VSS), D162.3 (VSS), D163.3 (VSS), D164.3 (VSS), D165.3 (VSS), D166.3 (VSS), D167.3 (VSS), D168.3 (VSS), D169.3 (VSS), D170.3 (VSS), D171.3 (VSS), D172.3 (VSS), J1.1, SW82.C, SW82.S1, U1.10 (V_{SS}), U1.15 (A0), U1.16 (A1), U1.17 (A2)
unnamed: D1.2 (A), SW1.2
unnamed: D2.2 (A), SW2.2
unnamed: D3.2 (A), SW3.2
unnamed: D4.2 (A), SW4.2
unnamed: D5.2 (A), SW5.2
unnamed: D6.2 (A), SW6.2
unnamed: D7.2 (A), SW7.2
unnamed: D8.2 (A), SW8.2
unnamed: D9.2 (A), SW9.2
unnamed: D10.2 (A), SW10.2
unnamed: D11.2 (A), SW11.2
unnamed: D12.2 (A), SW12.2
unnamed: D13.2 (A), SW13.2
unnamed: D14.2 (A), SW14.2
unnamed: D15.2 (A), SW15.2
unnamed: D16.2 (A), SW16.2
unnamed: D17.2 (A), SW17.2
unnamed: D18.2 (A), SW18.2
unnamed: D19.2 (A), SW19.2
unnamed: D20.2 (A), SW20.2
unnamed: D21.2 (A), SW21.2
unnamed: D22.2 (A), SW22.2
unnamed: D23.2 (A), SW23.2
unnamed: D24.2 (A), SW24.2
unnamed: D25.2 (A), SW25.2
unnamed: D26.2 (A), SW26.2
unnamed: D27.2 (A), SW27.2
unnamed: D28.2 (A), SW28.2
unnamed: D29.2 (A), SW29.2
unnamed: D30.2 (A), SW30.2
unnamed: D31.2 (A), SW31.2
unnamed: D32.2 (A), SW32.2
unnamed: D33.2 (A), SW33.2
unnamed: D34.2 (A), SW34.2
unnamed: D35.2 (A), SW35.2
unnamed: D36.2 (A), SW36.2
unnamed: D37.2 (A), SW37.2
unnamed: D38.2 (A), SW38.2
unnamed: D39.2 (A), SW39.2
unnamed: D40.2 (A), SW40.2
unnamed: D41.2 (A), SW41.2
unnamed: D42.2 (A), SW42.2
unnamed: D43.2 (A), SW43.2
unnamed: D44.2 (A), SW44.2
unnamed: D45.2 (A), SW45.2
unnamed: D46.2 (A), SW46.2
unnamed: D47.2 (A), SW47.2
unnamed: D48.2 (A), SW48.2
unnamed: D49.2 (A), SW49.2
unnamed: D50.2 (A), SW50.2
unnamed: D51.2 (A), SW51.2
unnamed: D52.2 (A), SW52.2
unnamed: D53.2 (A), SW53.2
unnamed: D54.2 (A), SW54.2
unnamed: D55.2 (A), SW55.2
unnamed: D56.2 (A), SW56.2
unnamed: D57.2 (A), SW57.2
unnamed: D58.2 (A), SW58.2
unnamed: D59.2 (A), SW59.2
unnamed: D60.2 (A), SW60.2
unnamed: D61.2 (A), SW61.2
unnamed: D62.2 (A), SW62.2
unnamed: D63.2 (A), SW63.2
unnamed: D64.2 (A), SW64.2
unnamed: D65.2 (A), SW65.2
unnamed: D66.2 (A), SW66.2
unnamed: D67.2 (A), SW67.2
unnamed: D68.2 (A), SW68.2
unnamed: D69.2 (A), SW69.2
unnamed: D70.2 (A), SW70.2
unnamed: D71.2 (A), SW71.2
unnamed: D72.2 (A), SW72.2
unnamed: D73.2 (A), SW73.2
unnamed: D74.2 (A), SW74.2
unnamed: D75.2 (A), SW75.2
unnamed: D76.2 (A), SW76.2
unnamed: D77.2 (A), SW77.2
unnamed: D78.2 (A), SW78.2
unnamed: D79.2 (A), SW79.2
unnamed: D80.2 (A), SW80.2
unnamed: D81.2 (A), SW81.2
unnamed: D82.4 (DIN), R4.2
unnamed: D82.2 (DOUT), D83.4 (DIN)
unnamed: D83.2 (DOUT), D84.4 (DIN)
unnamed: D84.2 (DOUT), D85.4 (DIN)
unnamed: D85.2 (DOUT), D86.4 (DIN)
unnamed: D86.2 (DOUT), D87.4 (DIN)
unnamed: D87.2 (DOUT), D88.4 (DIN)
unnamed: D88.2 (DOUT), D89.4 (DIN)
unnamed: D89.2 (DOUT), D90.4 (DIN)
unnamed: D90.2 (DOUT), D91.4 (DIN)
unnamed: D91.2 (DOUT), D92.4 (DIN)
unnamed: D92.2 (DOUT), D93.4 (DIN)
unnamed: D93.2 (DOUT), D94.4 (DIN)
unnamed: D94.2 (DOUT), D95.4 (DIN)
unnamed: D95.2 (DOUT), D96.4 (DIN)
unnamed: D96.2 (DOUT), D97.4 (DIN)
unnamed: D97.2 (DOUT), D98.4 (DIN)
unnamed: D98.2 (DOUT), D99.4 (DIN)
unnamed: D99.2 (DOUT), D100.4 (DIN)
unnamed: D100.2 (DOUT), D101.4 (DIN)
unnamed: D101.2 (DOUT), D102.4 (DIN)
unnamed: D102.2 (DOUT), D103.4 (DIN)
unnamed: D103.2 (DOUT), D104.4 (DIN)
unnamed: D104.2 (DOUT), D105.4 (DIN)
unnamed: D105.2 (DOUT), D106.4 (DIN)
unnamed: D106.2 (DOUT), D107.4 (DIN)
unnamed: D107.2 (DOUT), D108.4 (DIN)
unnamed: D108.2 (DOUT), D109.4 (DIN)
unnamed: D109.2 (DOUT), D110.4 (DIN)
unnamed: D110.2 (DOUT), D111.4 (DIN)
unnamed: D111.2 (DOUT), D112.4 (DIN)
unnamed: D112.2 (DOUT), D113.4 (DIN)
unnamed: D113.2 (DOUT), D114.4 (DIN)
unnamed: D114.2 (DOUT), D115.4 (DIN)
unnamed: D115.2 (DOUT), D116.4 (DIN)
unnamed: D116.2 (DOUT), D117.4 (DIN)
unnamed: D117.2 (DOUT), D118.4 (DIN)
unnamed: D118.2 (DOUT), D119.4 (DIN)
unnamed: D119.2 (DOUT), D120.4 (DIN)
unnamed: D120.2 (DOUT), D121.4 (DIN)
unnamed: D121.2 (DOUT), D122.4 (DIN)
unnamed: D122.2 (DOUT), D123.4 (DIN)
unnamed: D123.2 (DOUT), D124.4 (DIN)
unnamed: D124.2 (DOUT), D125.4 (DIN)
unnamed: D125.2 (DOUT), D126.4 (DIN)
unnamed: D126.2 (DOUT), D127.4 (DIN)
unnamed: D127.2 (DOUT), D128.4 (DIN)
unnamed: D128.2 (DOUT), D129.4 (DIN)
unnamed: D129.2 (DOUT), D130.4 (DIN)
unnamed: D130.2 (DOUT), D131.4 (DIN)
unnamed: D131.2 (DOUT), D132.4 (DIN)
unnamed: D132.2 (DOUT), D133.4 (DIN)
unnamed: D133.2 (DOUT), D134.4 (DIN)
unnamed: D134.2 (DOUT), D135.4 (DIN)
unnamed: D135.2 (DOUT), D136.4 (DIN)
unnamed: D136.2 (DOUT), D137.4 (DIN)
unnamed: D137.2 (DOUT), D138.4 (DIN)
unnamed: D138.2 (DOUT), D139.4 (DIN)
unnamed: D139.2 (DOUT), D140.4 (DIN)
unnamed: D140.2 (DOUT), D141.4 (DIN)
unnamed: D141.2 (DOUT), D142.4 (DIN)
unnamed: D142.2 (DOUT), D143.4 (DIN)
unnamed: D143.2 (DOUT), D144.4 (DIN)
unnamed: D144.2 (DOUT), D145.4 (DIN)
unnamed: D145.2 (DOUT), D146.4 (DIN)
unnamed: D146.2 (DOUT), D147.4 (DIN)
unnamed: D147.2 (DOUT), D148.4 (DIN)
unnamed: D148.2 (DOUT), D149.4 (DIN)
unnamed: D149.2 (DOUT), D150.4 (DIN)
unnamed: D150.2 (DOUT), D151.4 (DIN)
unnamed: D151.2 (DOUT), D152.4 (DIN)
unnamed: D152.2 (DOUT), D153.4 (DIN)
unnamed: D153.2 (DOUT), D154.4 (DIN)
unnamed: D154.2 (DOUT), D155.4 (DIN)
unnamed: D155.2 (DOUT), D156.4 (DIN)
unnamed: D156.2 (DOUT), D157.4 (DIN)
unnamed: D157.2 (DOUT), D158.4 (DIN)
unnamed: D158.2 (DOUT), D159.4 (DIN)
unnamed: D159.2 (DOUT), D160.4 (DIN)
unnamed: D160.2 (DOUT), D161.4 (DIN)
unnamed: D161.2 (DOUT), D162.4 (DIN)
unnamed: D162.2 (DOUT), D163.4 (DIN)
unnamed: D163.2 (DOUT), D164.4 (DIN)
unnamed: D164.2 (DOUT), D165.4 (DIN)
unnamed: D165.2 (DOUT), D166.4 (DIN)
unnamed: D166.2 (DOUT), D167.4 (DIN)
unnamed: D167.2 (DOUT), D168.4 (DIN)
unnamed: D168.2 (DOUT), D169.4 (DIN)
unnamed: D169.2 (DOUT), D170.4 (DIN)
unnamed: D170.2 (DOUT), D171.4 (DIN)
unnamed: D171.2 (DOUT), D172.4 (DIN)
unnamed: R1.1, U1.18 (~RESET)

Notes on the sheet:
SPACE
DISPLAY & ENCODER
PICO
ENTER
CONTROLLERS
RGB BACKLIGHT
LSHIFT
DECOUPLING
KEY MATRIX
HOLES
CAPSLCK
MCP

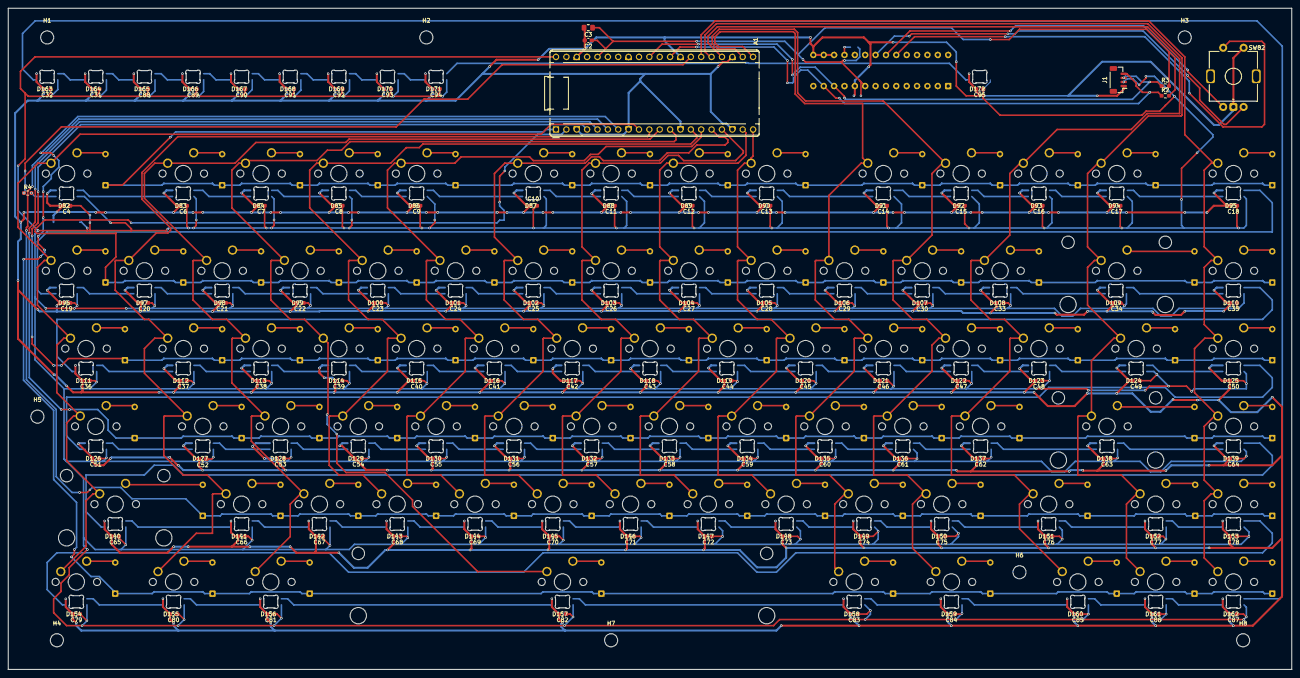
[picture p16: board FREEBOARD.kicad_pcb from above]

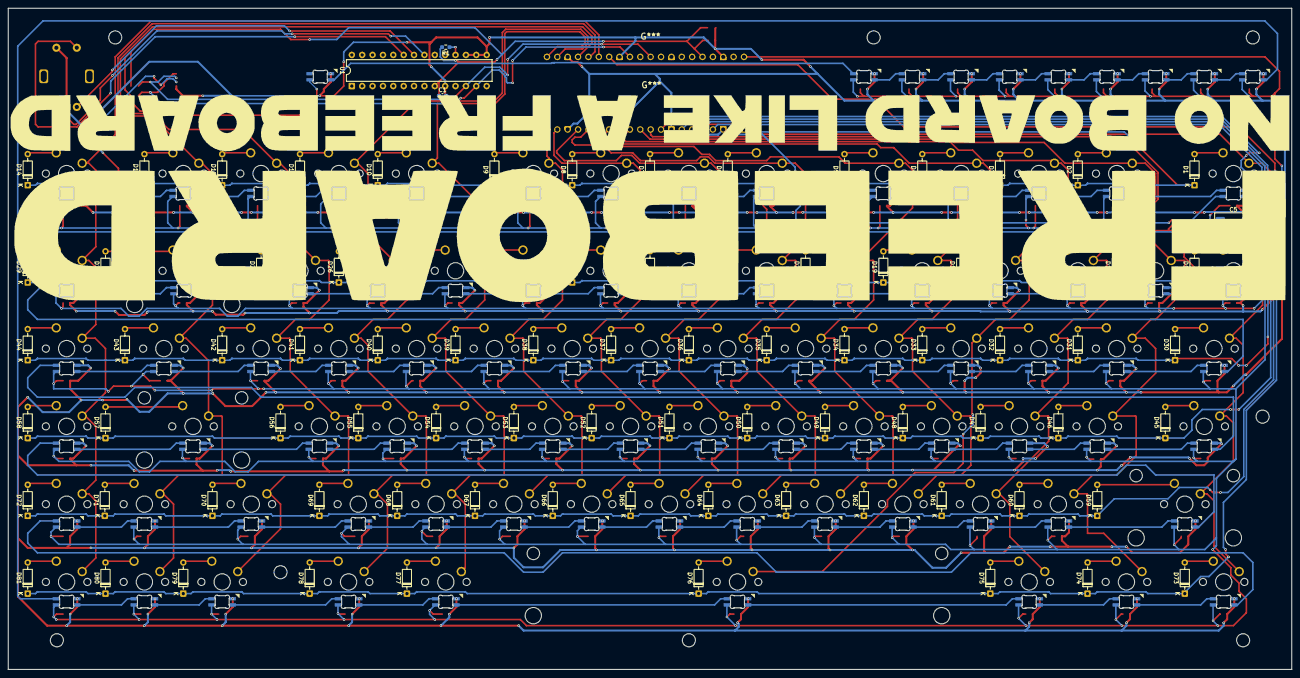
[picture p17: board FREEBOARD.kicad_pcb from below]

Board: 2 copper layers, 314.3 x 161.9 mm, 368 parts (85 on the bottom side), 203 nets.

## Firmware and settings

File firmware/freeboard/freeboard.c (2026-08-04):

#include "quantum.h"
#include "i2c_master.h"

#define MCP23017_IODIRA 0x00
#define MCP23017_GPPUA  0x0C
#define MCP23017_GPIOA  0x12

#ifdef RGB_MATRIX_ENABLE
led_config_t g_led_config = {
    {
        {      0, NO_LED,      1,      2,      3,      4,      5,      6,      7,      8,      9,     10,     11,     12,     13 },
        {     14,     15,     16,     17,     18,     19,     20,     21,     22,     23,     24,     25,     26,     27,     28 },
        {     29,     30,     31,     32,     33,     34,     35,     36,     37,     38,     39,     40,     41,     42,     43 },
        {     44,     45,     46, NO_LED,     47,     48,     49,     50,     51,     52,     53,     54,     55,     56,     57 },
        {     58,     59,     60, NO_LED,     61,     62,     63,     64,     65,     66,     67,     68,     69,     70,     71 },
        {     72,     73,     74,     75, NO_LED, NO_LED, NO_LED, NO_LED, NO_LED, NO_LED,     76,     77,     78,     79,     80 },
    },
    {
        {   4, 14 }, {  26, 14 }, {  40, 14 }, {  55, 14 }, {  70, 14 }, {  92, 14 }, { 106, 14 }, { 121, 14 },
        { 136, 14 }, { 158, 14 }, { 173, 14 }, { 187, 14 }, { 202, 14 }, { 224, 14 }, {   4, 26 }, {  18, 26 },
        {  33, 26 }, {  48, 26 }, {  62, 26 }, {  77, 26 }, {  92, 26 }, { 106, 26 }, { 121, 26 }, { 136, 26 },
        { 151, 26 }, { 165, 26 }, { 180, 26 }, { 202, 26 }, { 224, 26 }, {   7, 36 }, {  26, 36 }, {  40, 36 },
        {  55, 36 }, {  70, 36 }, {  84, 36 }, {  99, 36 }, { 114, 36 }, { 128, 36 }, { 143, 36 }, { 158, 36 },
        { 173, 36 }, { 187, 36 }, { 206, 36 }, { 224, 36 }, {   9, 45 }, {  29, 45 }, {  44, 45 }, {  59, 45 },
        {  73, 45 }, {  88, 45 }, { 103, 45 }, { 118, 45 }, { 132, 45 }, { 147, 45 }, { 162, 45 }, { 176, 45 },
        { 200, 45 }, { 224, 45 }, {  13, 55 }, {  37, 55 }, {  51, 55 }, {  66, 55 }, {  81, 55 }, {  95, 55 },
        { 110, 55 }, { 125, 55 }, { 140, 55 }, { 154, 55 }, { 169, 55 }, { 189, 55 }, { 209, 55 }, { 224, 55 },
        {   6, 64 }, {  24, 64 }, {  42, 64 }, {  97, 64 }, { 152, 64 }, { 171, 64 }, { 195, 64 }, { 209, 64 },
        { 224, 64 }, {   0,  0 }, {   9,  0 }, {  18,  0 }, {  28,  0 }, {  37,  0 }, {  46,  0 }, {  55,  0 },
        {  64,  0 }, {  73,  0 }, { 176,  0 },
    },
    {
        LED_FLAG_KEYLIGHT, LED_FLAG_KEYLIGHT, LED_FLAG_KEYLIGHT, LED_FLAG_KEYLIGHT, LED_FLAG_KEYLIGHT, LED_FLAG_KEYLIGHT, LED_FLAG_KEYLIGHT, LED_FLAG_KEYLIGHT,
        LED_FLAG_KEYLIGHT, LED_FLAG_KEYLIGHT, LED_FLAG_KEYLIGHT, LED_FLAG_KEYLIGHT, LED_FLAG_KEYLIGHT, LED_FLAG_KEYLIGHT, LED_FLAG_KEYLIGHT, LED_FLAG_KEYLIGHT,
        LED_FLAG_KEYLIGHT, LED_FLAG_KEYLIGHT, LED_FLAG_KEYLIGHT, LED_FLAG_KEYLIGHT, LED_FLAG_KEYLIGHT, LED_FLAG_KEYLIGHT, LED_FLAG_KEYLIGHT, LED_FLAG_KEYLIGHT,
        LED_FLAG_KEYLIGHT, LED_FLAG_KEYLIGHT, LED_FLAG_KEYLIGHT, LED_FLAG_KEYLIGHT, LED_FLAG_KEYLIGHT, LED_FLAG_KEYLIGHT, LED_FLAG_KEYLIGHT, LED_FLAG_KEYLIGHT,
        LED_FLAG_KEYLIGHT, LED_FLAG_KEYLIGHT, LED_FLAG_KEYLIGHT, LED_FLAG_KEYLIGHT, LED_FLAG_KEYLIGHT, LED_FLAG_KEYLIGHT, LED_FLAG_KEYLIGHT, LED_FLAG_KEYLIGHT,
        LED_FLAG_KEYLIGHT, LED_FLAG_KEYLIGHT, LED_FLAG_KEYLIGHT, LED_FLAG_KEYLIGHT, LED_FLAG_KEYLIGHT, LED_FLAG_KEYLIGHT, LED_FLAG_KEYLIGHT, LED_FLAG_KEYLIGHT,
        LED_FLAG_KEYLIGHT, LED_FLAG_KEYLIGHT, LED_FLAG_KEYLIGHT, LED_FLAG_KEYLIGHT, LED_FLAG_KEYLIGHT, LED_FLAG_KEYLIGHT, LED_FLAG_KEYLIGHT, LED_FLAG_KEYLIGHT,
        LED_FLAG_KEYLIGHT, LED_FLAG_KEYLIGHT, LED_FLAG_KEYLIGHT, LED_FLAG_KEYLIGHT, LED_FLAG_KEYLIGHT, LED_FLAG_KEYLIGHT, LED_FLAG_KEYLIGHT, LED_FLAG_KEYLIGHT,
        LED_FLAG_KEYLIGHT, LED_FLAG_KEYLIGHT, LED_FLAG_KEYLIGHT, LED_FLAG_KEYLIGHT, LED_FLAG_KEYLIGHT, LED_FLAG_KEYLIGHT, LED_FLAG_KEYLIGHT, LED_FLAG_KEYLIGHT,
        LED_FLAG_KEYLIGHT, LED_FLAG_KEYLIGHT, LED_FLAG_KEYLIGHT, LED_FLAG_KEYLIGHT, LED_FLAG_KEYLIGHT, LED_FLAG_KEYLIGHT, LED_FLAG_KEYLIGHT, LED_FLAG_KEYLIGHT,
        LED_FLAG_KEYLIGHT, LED_FLAG_UNDERGLOW, LED_FLAG_UNDERGLOW, LED_FLAG_UNDERGLOW, LED_FLAG_UNDERGLOW, LED_FLAG_UNDERGLOW, LED_FLAG_UNDERGLOW, LED_FLAG_UNDERGLOW,
        LED_FLAG_UNDERGLOW, LED_FLAG_UNDERGLOW, LED_FLAG_UNDERGLOW,
    }
};
#endif



static uint8_t encoder_state;
static int8_t  encoder_delta;
static bool    encoder_button;
static uint16_t encoder_button_timer;

void keyboard_post_init_kb(void) {
    i2c_init();

    // Keep every unused expander pin as an input. GPA0--GPA2 carry the
    // encoder and its switch, and use the MCP23017's internal pull-ups.
    uint8_t iodira = 0xFF;
    uint8_t gppua = 0x07;
    i2c_write_register(MCP23017_I2C_ADDRESS, MCP23017_IODIRA, &iodira, 1, 100);
    i2c_write_register(MCP23017_I2C_ADDRESS, MCP23017_GPPUA, &gppua, 1, 100);

    uint8_t data;
    if (i2c_read_register(MCP23017_I2C_ADDRESS, MCP23017_GPIOA, &data, 1, 100) == I2C_STATUS_SUCCESS) {
        encoder_state  = (~data) & 0x03;
        encoder_button = !(data & (1 << 2));
    }

    keyboard_post_init_user();
}

void matrix_scan_kb(void) {
    static const int8_t encoder_table[16] = {
         0, -1,  1,  0,
         1,  0,  0, -1,
        -1,  0,  0,  1,
         0,  1, -1,  0,
    };

    uint8_t data;
    if (i2c_read_register(MCP23017_I2C_ADDRESS, MCP23017_GPIOA, &data, 1, 100) == I2C_STATUS_SUCCESS) {
        uint8_t new_state = (~data) & 0x03;
        encoder_delta += encoder_table[(encoder_state << 2) | new_state];
        encoder_state = new_state;

        if (encoder_delta >= 4) {
            tap_code(KC_VOLU);
            encoder_delta = 0;
        } else if (encoder_delta <= -4) {
            tap_code(KC_VOLD);
            encoder_delta = 0;
        }

        bool new_button = !(data & (1 << 2));
        if (new_button != encoder_button && timer_elapsed(encoder_button_timer) >= 20) {
            encoder_button = new_button;
            encoder_button_timer = timer_read();
            if (encoder_button) {
                tap_code(KC_MUTE);
            }
        }
    }

    matrix_scan_user();
}

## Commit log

2026-08-04 PCB Files
    [FREEBOARD.kicad_pcb, FREEBOARD.kicad_sch]
2026-08-04 Key Matrix & LEDs
    [FREEBOARD.kicad_sch]
2026-08-04 PCB update
    [FREEBOARD.kicad_sch]
2026-08-04 Finished RGB LEDs
    [FREEBOARD.kicad_sch]
2026-08-04 Schematic Update
    [FREEBOARD.kicad_pcb, FREEBOARD.kicad_sch]
2026-08-04 Finished Schematic
    [FREEBOARD.kicad_sch]
2026-08-04 PCB Complete
    [FREEBOARD.kicad_pcb]
2026-08-04 CAD Update
    [Case - Base Case.step, Case - Base Case.stl, Case - BigStand1.step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]
2026-08-04 Repo Update
    [FREEBOARD.kicad_pcb, FREEBOARD.kicad_sch, FREEBOARD_bom.csv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]
2026-08-06 Links Update
    [FREEBOARD_bom.csv]
2026-08-06 Link Update
    [FREEBOARD_bom.csv]
